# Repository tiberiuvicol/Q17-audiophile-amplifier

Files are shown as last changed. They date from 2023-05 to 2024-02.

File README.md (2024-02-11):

# Q17-an audiophile approach to perfect sound

<a href="https://github.com/tiberiuvicol/Q17.3">Q17.3 is the latest implementation</a>

Q17

Q17 is a class B amplifier based on current dumping principle.<br>
Please refer to <a href="https://github.com/tiberiuvicol/Q17-audiophile-amplifier/blob/main/Project%20description.pdf">Project description.pdf</a> for project description.<br>
Use KiCad 6, or later, to open and edit source files.  KiCad 6 can be downloaded from CERN, https://www.kicad.org<br>
<b>LTSpice</b> - contain simulation asc file<br>
<b>Q17.7z</b> - <a href="https://forum.kicad.info/t/simulation-examples-for-kicad-eeschema-ngspice/34443">ngspice simulation</a> files for Q17. This will run directly in KiCad. Thank you, Holger Vogt !<br>
<b>KiCad source PS</b> - active rectification power supply KiCad source files<br>
<b>KiCad source</b> - Q17 amplifier KiCad source files<br>
<b>Q17_2final</b> - Q17 amplifier KiCad source files for dual output stage<br>
<b>Q17.pdf</b> - detailed presentation - bill of materials included<br>
<b>gerber-ps.zip</b> - production gerber for PCB active rectification power supply<br>
<b>Q17-Gerber.zip</b> - production gerber for Q17 amplifier with single output pair<br>
<a href="https://github.com/tiberiuvicol/Q17-audiophile-amplifier/blob/main/Q17-gerber-2pair.zip"><b>Q17-gerber-2pair.zip</b></a> - production gerber files for Q17 with dual output pair stage<br>
<b>Q17_dimensions.pdf</b> - PDf file with most important PCB dimensions<br>
Important ! - Amplifier is more stable with R32=0ohm



<br>
Click & Order your Q17 with dual output pair PCB @ <a href="https://www.pcbway.com/project/shareproject/Q17__a_QUAD405_audiophile_approach.html">PCB from PCBWay</a><br>
Purchase parts (for one channel) with one click from mouser ->> https://www.mouser.com/ProjectManager/ProjectDetail.aspx?AccessID=1f37a45393 <br>
For STEREO or MULTICHANNEL multiply the order with the same parts. <br>
<br>
<br>
<b>Q&A collected from mail</b><br>
<br>
Q: Why no dc blocking input capacitor?<br>
A: <i>Please consider that Q17 first stage make use of an operational that have a C7=1uF capacitor in negative loop. <br>
This already make a dc block and we have a non polar capacitor C2&C22 in dc servo as well.<br>
On other hand, if there is any dc at amplifier input, you should look on your audio source and eliminate it. Do not try to “solve” previous stage problems by "playing safe" at the amplifier input.</i><br>
<br>
<br>
Q: Why no voltage/ESD input protection ?<br>
A: <i>A voltage/ESD can be made by using zener or reverse polarised diodes. The issue with this approach is that any reverse polarised p/n junction (diode etc) will have high parasitic capacitance modulated by voltage and this highly degrade amplifier performance. How to work around this ? Use a good R-2R Volume Controller with constant output impedance.</i><br>
<br>
<br>
Q: Any amplifier need input LPF, otherwise EMI will affect SNR.  Q17 do not have one, therefore it is poorly designed. Why Q17 do not have input LPF?<br>
A: <i>Please do not generalise. The world is not black and white.The role of LPF is to block any unwanted frequencies to enter in amplifier. <br>
A LPF must be designed such way that will not be affected by input impedance. This is not the case with a potentiometer. Does not matter how good this potentiometer is, his attenuation will affect LPF and therefore amplifier bandwidth. This is very audible at low level volume.<br>
The classic way on how a potentiometer is implemented, is that he offer constant input impedance and variable output impedance toward amplifier input. The down side is that, even you go for a high input impedance, at low audio levels input LPF will reach audio band affecting amplifier bandwidth. This is translated in poor audio performance at low audio levels.<br>
This issue was addressed in Maya volume controller that make use of an R-2R resistive network allowing constant output impedance with high input variable impedance.<br>
Beside this, input cable parasitic capacitance together with high amplifier impedance is enough to form a HF-LPF. Output operational LPF at ~125KHz will clean any noise further.</i><br>
<br>
<br>
Q: Could you please recommend me a potentiometer ?<br>
A: <i>Best attenuator will be a R-2R one with constant output impedance. If you want to go cheap please use a 50K log ALPS.</i>
<br>
<br>
Q: Why there is no super diode ?<br>
A: <i>A super diode is usually made with a BJT, where his Vbe variation with temperatures is used to adjust output stage bias. Unfortunately this is highly nonlinear and will modulate, with Vcb voltage (again reverse polarised p/n junction), output stage bias. While this is very efficient, will highly degrade audio performance. My preference is to have plain and simple resistors, with no capacitor decoupling between output mosfet gates.</i><br>
<br>
<br>
Q: What about transitory power ON/OFF ? <br>
A: <i>For this there are Q13&Q14. These have double role.<br>
One is to ensure soft start and soft power off using RC made with R29C13 and R30C14. <br>
This can be seen at amplifier turn on, D1 & D4 will light after ~1s.<br>
Second role for Q13&Q14 is to act as super-capacitors, ensuring smooth power supply for class A and input stage.</i><br>
<br>
<br>
Q: Why no protection zeners on all mosfets ?<br>
A: <i>Some mosfets need Vgs protection while other do not need.<br>
Let’s start with ones that do not need and later the ones that may need.<br>
Q1 and Q4 are part of regulators and Vgs is already limited by 18V zeners.<br>
Q8 is part of cascode and his Vgs is already limited by positive zener regulator to 18V. You may say it is high, but Q8 source is already lifted above ground by Q7.<br>
Q9 and Q11 are part of current mirror. Q9’s Vgs is limited by Q10 + Vbe and Q10 by Q9 Vgs + VR3. This will not exceed 4V.<br>
Q5 Vgs is also limited by Q9 Vds + VR3. Where Q9 Vds = Q10 Vgs. Therefore, mirror with Q9&Q10 act as Vgs limiter for Q5.<br>
Q6 may need a zener to limit his Vgs due during a transitory turn on his Vgs may be higher, but for a soft turn on there are Q13&Q14.<br>
Q13&Q14 obviously need Vgs limiters because at power on, while C13&C14 are charging, Vgs will be above 45V. For such reason there are zener D4&D5, limiting Vgs to a value that keep Q13&Q14 on safe side.<br>
Q15&Q16&Q17&Q18 are output transistors that may need protection zener. These are high transconductance mosfets that indeed will deliver very high transitory currents. Here the man advantage is that we are running these in class B with very low bias current. Turn on/off transitory is also softened by Q13&Q14 trough class A stage made with Q5&Q6.<br>
On other hand, I prefer to run output stage without protection zener, due any zener internal parasitic capacitance is modulated with voltage. Any reverse biased diode act like a varicap. This is translated in muddy highs.</i><br>
<br>
<br>
Q: Why no output inductor ?<br>
A: <i>This is a highly debatable question.<br>
I’m a nerd audiophile. I like good sound more than “playing safe”.<br>
However, your speaker cables have already an important inductance and parasitic capacitance that must considered. <br>
In some particular cases adding an output inductor may be needed, but these are very … few particular ones.<br>
To be short, Q17 with no coil sound better.</i><br>
<br>
<br>
Q: May I use Lateral MOSFET's in ouput stage ?<br>
A: <i>No, you do not, the PCB was designed for Vertical MOSFET. Lateral mosfet transistor's have different piout than Vertical MOSFET.<br>
  PCB need to be redesigned to accomodate Lateral's, for both Class A and output Class B stage.
  Laterals have lower Vgsth than Verticals, hence for laterals, R11 and R12 must be between 9.1 and 10 ohm.</i><br>
<br>
<br>
Q: Why no embedded protection in your schematic ?<br>
A: <i>This again due sound quality. There is always a trade between playing safe and having best sound.<br>
I like to have best sound even I do not play safe and currently market offer a wide range of speaker protection modules.<br>
Simplest protection would be to use a fast fuse (3A-5A) at amplifier output.</i><br>
<br>
<br>
Q: How much capacitance I may put in power supply ?<br>
A: <i>This is related to your power transformer. A huge capacitance must be charged to be efficient.  For a transformer with 3A in secondary, I would say 20mF per rail is enough.</i><br>
<br>
<br>
Q: Is there any sound difference between a normal bridge and Saligny synchronous rectifiers ?<br>
A: <i>Yes, Saligny rectifiers are far superior and bring important sonic improvement.</i>
<br>
<br>
Q: It is Q17 quiet ?<br>
A: <i>Yes it is. No fass no buzz, even with high SPL speakers >95dBm.</i><br>
<br>
<br>
Q: May you recommend a transformer ?<br>
A: <i>Any well made 300VA transformer, with 2 separate secondaries at min.36Vac - max.42Vac.</i><br>
<i>For my projects I order at https://petra-toroid.ro/?lang=en they ship worldwide.</i><br>
<i>How to order:</i><br>
<i>- go to https://petra-toroid.ro/contact/?lang=en use form or email</i><br>
<i>- mention that you want to order one or two 300VA trafo</i><br>
<i>- primary 115Vac or 230Vac, depending on the mains voltage in your region</i><br>
<i>- 2 separate 36Vac secondaries</i><br>
<i>- optional magnetic shielding</i><br>
<i>- mention that application will be for audio</i><br>
<i>Other sources are: https://www.audiophonics.fr/en/toroidal-transformers/toroidal-transformer-300va-2x38v-p-5548.html</i><br>
<i>Toroidy https://sklep.toroidy.pl/en_US/c/Toroidal-transformers-SUPREME-AUDIO-GRADE-V2/99</i><br>
<i>Trafco http://www.trafco.rs/torusni-en.php</i><br>
<br>
<br>
Q: Can Q17 drive ESL speakers ?<br>
A: <i>Yes, will drive ESL speakers very well. Thanks to high transconductance mosfet’s, Q17 will offer excellent performance on ESl speakers.</i><br>
<br>
<br>
Q: What make Q17 special ?<br>
A: <i>His topology, class B operation, PCB with embedded coil and innovative active power supply. </i><br>
<br>
<br>
Q: Is Q17 power eficient ?<br>
A: <i>Yes, it is. Thanks to class B operation and Saligny synchronous rectification, Q17 is a modern amplifier with low power consumption.</i><br>
<br>
<br>
Q: My left channel is warmer, ~5Celsius, than the right channel. How I can match them ?<br>
A: <i>Is this a really issue ? No.
Left/Right channel temperature difference is mainly due slightly different "bias" in output stage. Even Q17 is running in class B, each mosfet have different Vgs treshold and this is translated in more or less Ids current. You may start by matching Q12 to have very appropiate Vbe's, than make sure R11, R12, R13 are matching R11, R12, R13 from other channel. Finnaly, match output Q15 .. Q18 mosfets between channels.</i><br>
<br>
<br>
Q: Voltage over R3 should be around 0.6Vdc, but mine is way off, how may I adjust this ?<br>
A: <i>In order to have 0.6Vdc over R3, Q9 and Q11 must be matched (same Vgth), only then voltage over R3 is given only by Q10Vbe. Therefore please match Q9 and Q11 to have same Vgsth=Voltage gate to source threshold. </i><br>
<br>
<br>
Q: Where you you place this amplifier in term of value ?<br>
A: <i>A well executed Q17, will be better or at least on pair with some $5 digit amplifiers.</i><br>
<br>
<br>
Thank you for reading ! <br>
If you have built this amplifier I would love to see your Q17 implementation. :-) <br>
<br>
Many thanks to those who built Q17 and shared their experience. Here is the builders feedback:<br>
https://www.diyaudio.com/community/threads/q17-an-audiophile-approach-to-perfect-sound.374507/page-72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
<br>
https://www.diyaudio.com/community/threads/q17-an-audiophile-approach-to-perfect-sound.374507/page-114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
<br>

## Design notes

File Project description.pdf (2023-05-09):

Q17 - audiophile approach to perfect sound

Hard to prove statements:
I know what I saw ! Ufologist I know what I hear ! Audiophile

by audiophile Tiberiu Vicol & ChatGPT This document was updated on 09.May.2023

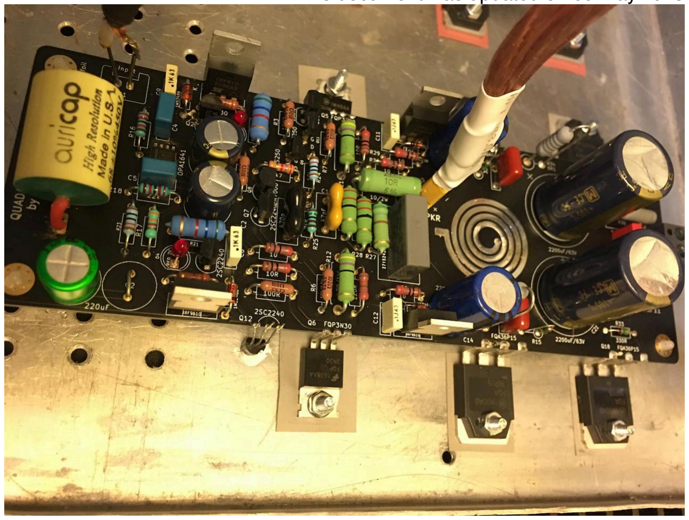
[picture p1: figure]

Introduction:

Q17 is a class B amplifier based on the current dumping principle.

Initial technical requirements:

- Stable operation: The amplifier must remain stable under any operational condition, with no oscillation.
- Minimum 100W in 8ohm at 1kHz: This should be sufficient for audiophiles with "impossible to drive" speakers.
- Frequency response cutoff of 10Hz - 100kHz: This will allow for a decent slew rate.

- IMD (Inter-Modulation Distortion) under 0.01%
- THD (Total Harmonic Distortion) under 0.01% at 1W and full power
- Design must be affordable, using readily available THT or SMD components or equivalents.
- Cost-effective and easy to build: High-end audio must be affordable.
- Open source: Let's offer everything - schematic, simulation, source PCB files, and bill of materials.
- Designed using LTspice simulation with final touch by extensive bench measurements and testing. Starting with KiCad 6.0.2, ngspice simulation is possible, and files have been made available by Holger Vogt: https://forum.kicad.info/t/simulation-examples-foricad-eeschema-ngspice/34443 (https://forum.kicad.info/t/simulation-examples-for-icad-eeschema-ngspice/34443)
- Final design decisions are always made using my platinum
ears. ;-) This means that Q17 is designed by comparing different topologies, and the final decision is taken not by measurement, but by listening. Q17 is indeed designed by ear. :-D

And here are the on-ear requirements:

Sound quality is of paramount importance. The amplifier must sound excellent at any level, without causing listening fatigue. The sound must be vivid, with a full body and plenty of harmonics with long decay, while maintaining resolution and clarity from top to bottom. Each instrument must sound natural, clearly separated, and easy to locate in space, even in large orchestras.

- No hiss or buzz: Poor rectification and filtering may result in unwanted noise.
- Microdynamic: This is challenging. The rhythm must be clear and distinct at any volume. I don't want flat, compressed, or lifeless sound. This is often related to negative feedback (NFB). In my opinion, NFB is only partially true, and it largely depends on how it is used along with other factors. High-quality power supply filter capacitors may also help.
- Macrodynamic linearity: The amplifier must be capable of going from low to high power levels instantly, without distortion or compression. It must provide the feeling of unlimited power. This is mainly related to the power supply. If the amplifier is capable of delivering power, the power supply must be able to handle it as well.

- Resolution: I prefer an amplifier that offers both resolution and fullbodied instruments, without losing harmonics and decay. Welldesigned single-ended direct-heated triodes (SEDHT) are capable of achieving this, and I want the same from my amplifier. I know this is another challenging requirement. Intermodulation distortion plays a role here. Low IMD always leads to top resolution, but sometimes musicality can be lost.

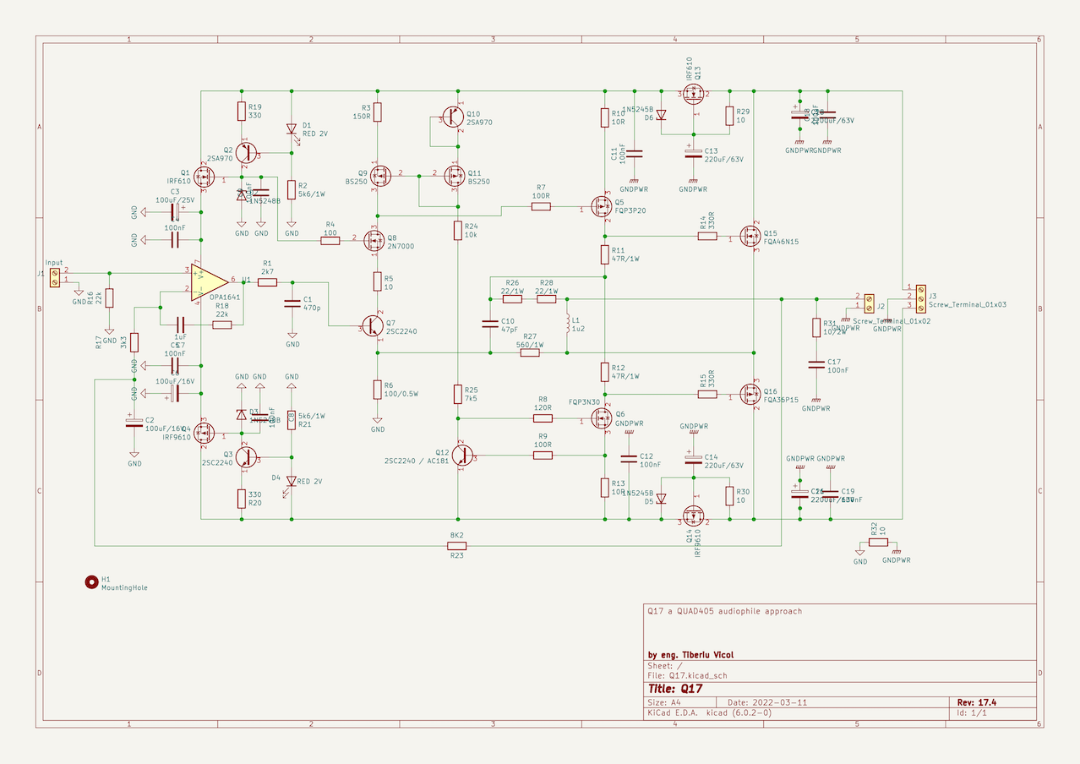
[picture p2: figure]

Q17 with output single pair of Fairchild’s

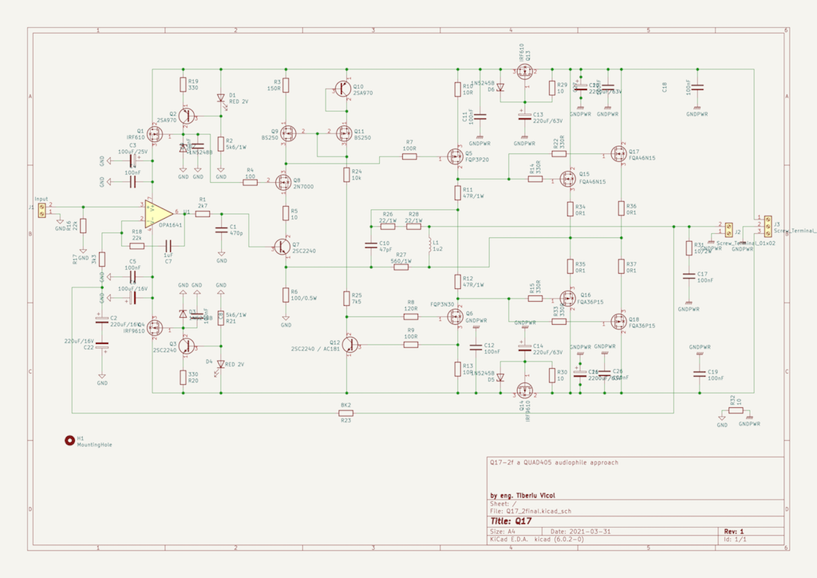
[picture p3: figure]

Q17 with output double pair of Fairchild’s

## Functional Description:

### Q17 is designed to deliver music at the highest audio performance, and

this design does not follow the "amplifier design book." Intentionally,

### the input is DC coupled, it has no input LPF, and does not make use of diodes or Vbs multiplier for thermal compensation. Q17 will run in class B, even though the output devices are MOSFETs with a very high Vgs

threshold. As far as I know, this has never been attempted before.

### Please correct me if I'm wrong. Q17 is divided into two separate

sections, which we will call Section One and Section Two.

Section One is made with the operational amplifier OPA1641. Today,

OPA1641 is one of the best opamps on the market. In fact, it is so good that a discrete circuitry will barely come close. OPA1641 is a JFET input operational amplifier that, apart from technical specifications, sounds very good and is cost-effective too. We are not driving a low impedance output, and there are no thermal issues. Those who do not like JFET

sound may try LME49990. This sounds great as well.

In my humble opinion, phase accuracy is very important. Therefore,

Q17 is not inverted and will preserve the original phase of the signal.

The input impedance is given by R16 = 22K. This is a good trade between high impedance and thermal resistor noise. You want higher input impedance? You can go as high as 47K. Use a good metal foil resistor here, and it should be enough. R17 and R18 are part of operational negative feedback and will set the gain to (R17+R18)/ R17=7.6. Many operational amplifiers will not be stable at low gain, and the stability limit is usually at a gain higher than 5. 7.6 will offer good

sensitivity, and we are on the safe side, away from any oscillation.

### Through R30, R25, and C3, the input operational will have a second role, acting as a DC servo. C3 must be bipolar, and I recommend using a good one like Nichicon MUSE. However, two normal polarized electrolytics connected in series will work just fine. For this use, low-

voltage electrolytics in the range of 6.3V-10VDC.

### R1C1 forms a low-pass filter with a cutoff frequency of 125kHz. This RC filter is the main load for the operational and will also limit the whole

amplifier's full bandwidth. C1 must be silver-mica or polystyrene.

### The operational is fed by two "reasonably low noise" regulators. The operational will not draw more than 10mA per raw, but its sonic

performance is highly dependent on the quality of these regulators. So,

### I have invested some time and parts to get the best topology for sound

versus price compromise.

Here is how it works. Regulation is ensured by 18V zeners D2 and D3, which are fed by a constant current source at around 4.2mA. Q2, D1,

### R19, and R2 (respectively Q3, D4, R20, and R21 for the negative rail) form a simple current source. D1 and D4 are red LEDs with Vf~2V. It is well-known that an LED is a reliable low-noise voltage reference. The current through the zener diode will be (LedVf-Q7Vbe)/R19 = (2-0.6)/330

= 4.2mA. This reference voltage is used by two MOSFETs, Q1 and Q4,

### respectively, to deliver higher current to OPA1641. IRF610/IRF9610 are a bit overkill here but are easy to find and cheap enough. These will run

warm but do not need a heatsink.

### Here is one of my first audiophile observations: MOSFET regulators sound better than bipolar regulators. They do not measure better, but

they sound better.

### Section two starts with a cascode formed by Q7 and Q8. This stage offers high gain, high output impedance, and high open-loop bandwidth

and may be a challenge to keep it out of oscillation. For this reason, R5 is there. This will lower the gain and increase stability at the cost of some distortion. In place of Q7, some inexpensive transistors BC5xx/ BC8xx can be used, as maxVce > 45V is the only restriction. From a sonic point of view, some cascodes may kill the "soul of music," in other words, offer a less vivid sound. Things are going far better if you use a MOSFET as the top active device. This will preserve dynamics at

any level.

### The cascode - Q7 & Q8 - stage has a high output impedance, therefore

it is fed by a constant current source made by Q10 and R3 at approx.

### 4.5mA. Q10 can be any low-cost, high-beta PNP BJT. Yes, any PNP, no

constraints.

### The CCS current is mirrored to Q12 by Q9 & Q11 through R24 & R25. In fact, the heart of Q17 is around this CCS+ current mirror. A current mirror that can be made with high-beta PNP transistors or P-channel MOSFET. You may need to pair these transistors to have same Vbe or

Vgs at ˜5mA.

I tried both. BJT mirror is very precise and offers a lush sound. For MOSFET, I used BS250P, and in this case, sound is deeper with a better midrange. Micro-dynamics seem to be higher too. After extensive listening sessions and some burn-in, I can confidently say that I will stay with MOSFET mirror. Take care of BS250P numbering termination as

this is different for manufacturers - see Vishay and Diodes.

### Instead of R24 & R25, you may use a single 1W resistor. This was split

in two to distribute power dissipated.

### Next is a class A stage. Here a single modern high-transconductance

MOSFET will do an excellent job, at the cost of some input capacitance.

### MOSFETs create more even-order harmonics compared to bipolar's too. As I care more about harmonic content than THD, here is my

preference for MOSFET.

### The quality of these MOSFETs may dramatically influence the amplifier's sonic signature, and these have been chosen after long

listening sessions.

### The P-channel MOSFET Q5 is a class-A active device, and from my observation, the P-channel FQP3P20 is slightly more linear than the Nchannel FQP3N30. However, at the current time (2021), we do not have

too many options. Toshiba's lateral MOSFETs (2SJ76, 2SJ77, 2SJ78,

### 2SJ79, and 2SK213, 2SK214, 2SK215, 2SK216) have long been obsolete. If you can source them, use them, but don't set your

expectations too high. These will not sonically exceed the FQP's.

### However, if you do use them, some capacitor compensation may be

needed to keep them from oscillating.

Q5 is fed by a 60mA CCS formed by Q12 and Q6. Q12 Vbe is the main reference in this CCS and can be used as thermal compensation for the final stage too. Again, there are no constraints for Q12. It can be any high-beta, low-voltage, NPN BJT. The CCS current can be calculated by Q12Vbe/R13 and would be around 60mA. This will push Q5's operation in class A and offer enough juice to drive the final dumper stage. Q5 and Q6 will dissipate 3W and must be mounted on a

heatsink.

### Q12 must also be mounted on a heatsink as it will be used to

compensate for final stage thermal runaway.

### Changing R13 to 2 ohms, a germanium AC181 can be used here as better temperature compensation. I must mention that this mod will not bring "germanium sound" into this amplifier. Sorry, germanium lovers!

### R9 is there as a base stopper and to avoid any possible oscillation. R7

and R8 are gate stoppers too.

### The Q17 amplifier runs in class B. There is no bias needed, and the Q17

amplifier may accept a very wide range of output MOSFET transistors.

Choosing the final pair Q15 & Q16.

I'm a big fan of lateral MOSFETs made by Semelab-Semefab-Exicon-Magnatec, whatever company is behind. This Scottish company is one of the last to make very good high-power lateral MOSFETs. I proudly used them in many amplifiers, and they sound exceptional. The main goal of Q17 is to be affordable, and these laterals, like many other good things, are not so cheap. They are very rugged and allow a high level of

"torture" and make things sometimes easy. No protections are needed.

### But... there is a "but." They have a small transconductance. You need to use double die and parallel a few of them to get some decent transconductance because audiophile speakers make use of

### complicated crossovers that like a lot of current in the most unexpected

frequencies.

Fairchild, now ON Semiconductor, was a great company and one of their legacies is FQA46N15 and FQA36P15. If you think these are P/N pairs, you are wrong. There is no such P/N perfect match in the real world, but we can choose the closest ones. These are marketed as "Fairchild Semiconductor's proprietary planar stripe and DMOS technology," with a small remark that they may be suitable for audio

amplifiers as well.

### FQA46N15 has a regular transconductance of 36 Siemens, while Exicon double die ECW20N20 has a maximum of 4 Siemens. This is equivalent to 9 double die laterals. Yes, very impressive! FQA36P15 has a regular transconductance of 19.5 Siemens, while Exicon double die ECW20P20

has a maximum of 4 Siemens. This is equivalent to 4 double die laterals.

In the "dark side" of Mouser, some beasts may leave these Fairchild's in the dust. These are made by IXYS, and a pair could be IXFK220N20X3 and IXTK120P20T. These exhibit over 120 Siemens of transconductance and are capable of transforming your amplifier into a real welding machine. No joke at all. If your speakers have never been

moved before, use a pair of these and shake your world, your walls, your neighbor...

### Through R11 and R12, these devices will be biased near class A operation. Both FQA46N15 and FQA36P15 have a Vgs - threshold voltage between 3V and 4V. I found that the P channel FQA36P15 will

open around 3V, while the FQA46N15 will need 100mV-300mV more.

### (To have both running at the same level, R11 may be increased to 51ohm or more.)

### Obviously, Q15 and Q16 must be mounted on a large heatsink. R31C17 is the well-known Zobel filter. C17 quality is important. Use a good propylene or polystyrene capacitor here. My preference is polystyrene Multicap RTX series. If you do not want to invest too much, go for

Arcotronix.

### R26, R27, R28, C10, and L1 form the current dumping bridge. R27 and R6 are part of section 2 negative feedback. This sets the entire amplifier gain to [(R17+R18)/R17]x[{R27+R6)/R6]=45.6, enough for the amplifier

to reach 100W/8ohm at 0.7V input.

### Q13 and Q14 are capacitor multipliers and are there to reduce power supply ripple. (These are not needed if you use synchronous rectification - see below.) During power on, the gate to source voltage on Q13 and Q14 may easily exceed 10V and may damage these

MOSFETs. For this reason, D5 and D6 are there to protect.

### You may have noticed that there are R4, R7, R8, R9, R14, and R15 as gate or base stoppers. I always prefer gate stoppers to compensate with capacitors. R32 will separate the signal ground plane from the

power ground plane. There are no special requirements for this one.

### Please note that R32 is 0ohm and not 10ohm as in presented

schematic.

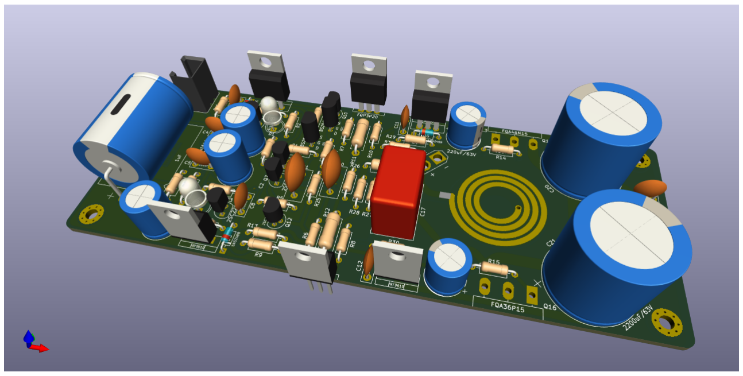
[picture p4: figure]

PCB design

During the COVID-19 lockdown, I had enough time to learn KiCad. KiCad runs on any operating system and is open source. This offers flexibility, scalability, and security. KiCad is a great tool.
I have designed this project in KiCad 5.99-nightly. To open the files, you need at least 5.99. This is already compatible with the upcoming KiCad 6, which is a huge step forward.
I opted for separate small and high signal ground planes. Ground planes are a good solution to avoid ground loops and offer excellent EMI reduction. For the best noise reduction, small signal GND makes use of top and bottom ground planes.
The PCB embeds an L1 inductor that is part of the error correction bridge. This will ensure good tolerance and optimal geometric design.

Yes, a PCB inductor will have the right shape for a near-to-ideal inductor. The truth is that I'm lazy to wire-wind coils. Having this embedded in the PCB will help lazy people like me a lot, but what I said earlier is still valid. A PCB coil is better. In a separate document, I have detailed how to create and embed inductors in KiCad.
The PCB offers the option to install several C7 types. Use propylene at any voltage > 50V. C17 must be propylene, preferably FKP, or polystyrene at a voltage > 100V.
OPA1641 is the single SMD part, and the PCB does not offer the option to install a THT one. But as long as I offer the source files for this project, you are invited to modify and redesign as you wish.

Bill of materials for Q17

D1,4 - LED RED 2V - https://ro.mouser.com/ProductDetail/Vishay-Semiconductors/TLHR5200?qs=GMckgg3bfZPthGr1cDR0RA%3D%3D (https://ro.mouser.com/ProductDetail/Vishay-Semiconductors/TLHR5200?qs=GMckgg3bfZPthGr1cDR0RA%3D%3D) D2,3 - 1N5248B - https://ro.mouser.com/ProductDetail/ON-Semiconductor-Fairchild/1N5248B?qs=G5AQjGfRJcJY58VFTX%252BkdQ%3D%3D (https://ro.mouser.com/ProductDetail/ON-Semiconductor-Fairchild/1N5248B?qs=G5AQjGfRJcJY58VFTX%252BkdQ%3D%3D)
D5,6 - 1N5245 - https://ro.mouser.com/ProductDetail/ON-Semiconductor-Fairchild/1N5245BTR?qs=jumAldekxNAufOthuRVeGQ%3D%3D (https://ro.mouser.com/ProductDetail/ON-Semiconductor-Fairchild/1N5245BTR?qs=jumAldekxNAufOthuRVeGQ%3D%3D)
Q7,12 - KSC1845 - https://ro.mouser.com/ProductDetail/ON-Semiconductor-Fairchild/KSC1845FTA?qs=UMEuL5FsraDCmxWozTypUA%3D%3D (https://ro.mouser.com/ProductDetail/ON-Semiconductor-Fairchild/KSC1845FTA?qs=UMEuL5FsraDCmxWozTypUA%3D%3D)
Q8 - 2N7000 - https://ro.mouser.com/ProductDetail/ON-Semiconductor-Fairchild/2N7000TA?qs=iN0KuJO79KZfCWVKA48bEg%3D%3D (https://ro.mouser.com/ProductDetail/ON-Semiconductor-Fairchild/2N7000TA?qs=iN0KuJO79KZfCWVKA48bEg%3D%3D)
Q2,Q10 - KSA992 - https://ro.mouser.com/ProductDetail/ON-Semiconductor-Fairchild/KSA992FBTA?qs=BiJXFBt7cx0C7PSFUPmr1w%3D%3D (https://ro.mouser.com/ProductDetail/ON-Semiconductor-Fairchild/KSA992FBTA?qs=BiJXFBt7cx0C7PSFUPmr1w%3D%3D)
Q9,11 - BS250P - https://ro.mouser.com/ProductDetail/Diodes-Incorporated/BS250P?qs=OlC7AqGiEDnRUFCQhRDfhA%3D%3D (https://ro.mouser.com/ProductDetail/Diodes-Incorporated/BS250P?qs=OlC7AqGiEDnRUFCQhRDfhA%3D%3D)
Q1,13 - IRF610 - https://ro.mouser.com/ProductDetail/Vishay-Siliconix/IRF610PBF-BE3?
qs=%2Fha2pyFadugbZUitPAu%252BTEPjT5SopLZ8qDnf9IMIvY8%3D (https://ro.mouser.com/ProductDetail/Vishay-Siliconix/IRF610PBF-BE3) Q4,14 - IRF9610 - https://ro.mouser.com/ProductDetail/Vishay-Semiconductors/IRF9610PBF?qs=cvaI6ThkwxtWoLkQbU%2FdsA%3D%3D (https://ro.mouser.com/ProductDetail/Vishay-Semiconductors/IRF9610PBF?qs=cvaI6ThkwxtWoLkQbU%2FdsA%3D%3D) Q5 - FQP3P20 - https://ro.mouser.com/ProductDetail/onsemi-Fairchild/FQP3P20?qs=mdiO5HdF0Ki1WoTNCOatYg%3D%3D (https://ro.mouser.com/ProductDetail/onsemi-Fairchild/FQP3P20?qs=mdiO5HdF0Ki1WoTNCOatYg%3D%3D)
Q6 - FQP3N30 - https://ro.mouser.com/ProductDetail/onsemi-Fairchild/FQP3N30?qs=FOlmdCx%252BAA1dVHDhvU%252BUcw%3D%3D (https://ro.mouser.com/ProductDetail/onsemi-Fairchild/FQP3N30?qs=FOlmdCx%252BAA1dVHDhvU%252BUcw%3D%3D)
Q15 - FQA46N15 - https://ro.mouser.com/ProductDetail/ON-Semiconductor-Fairchild/FQA46N15?
qs=%2Fha2pyFaduimCeOyuw0xouriGUKJcVVjoz%2FqQ0BKQtc%3D (https://ro.mouser.com/ProductDetail/ON-Semiconductor-Fairchild/FQA46N15) Q16 - FQA36P15 - https://ro.mouser.com/ProductDetail/ON-Semiconductor-Fairchild/FQA36P15?
qs=%2Fha2pyFadugPFcM3hvKrsP2cJsnMpKcpv1XDSGf5JCo%3D (https://ro.mouser.com/ProductDetail/ON-Semiconductor-Fairchild/FQA36P15)

U1 - OPA1641 - https://ro.mouser.com/ProductDetail/Texas-Instruments/OPA1641AIDR?
qs=sGAEpiMZZMutXGli8Ay4kFRPeV04IrZfqfNgaiEGnmE%3D (https://ro.mouser.com/ProductDetail/Texas-Instruments/OPA1641AIDR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)

C17 - 100nF - https://ro.mouser.com/ProductDetail/KEMET/R76MI31005050J?qs=pUKx8fyJudAaVipAdJ8Rqw%3D%3D (https://ro.mouser.com/ProductDetail/KEMET/R76MI31005050J?qs=pUKx8fyJudAaVipAdJ8Rqw%3D%3D) C4,5,8,9,11,12,18,19 - 100nF - https://ro.mouser.com/ProductDetail/KEMET/PHE426DJ6100JR05?qs=PoZJcSwa6DzVkLIswxOBtw%3D%3D (https://ro.mouser.com/ProductDetail/KEMET/PHE426DJ6100JR05?qs=PoZJcSwa6DzVkLIswxOBtw%3D%3D)
C10 - 47pF - https://ro.mouser.com/ProductDetail/Cornell-Dubilier-CDE/CD15ED470JO3?qs=JlSiUoO6twmzsCndHIj%2FhA%3D%3D (https://ro.mouser.com/ProductDetail/Cornell-Dubilier-CDE/CD15ED470JO3?qs=JlSiUoO6twmzsCndHIj%2FhA%3D%3D)
C7 - 1uF - https://ro.mouser.com/ProductDetail/Cornell-Dubilier-CDE/930C1W1K-F?qs=oi6qnwyrdkzUKQFAck35kQ%3D%3D (https://ro.mouser.com/ProductDetail/Cornell-Dubilier-CDE/930C1W1K-F?qs=oi6qnwyrdkzUKQFAck35kQ%3D%3D)
C1 - 470pF - https://ro.mouser.com/ProductDetail/Cornell-Dubilier-CDE/CD15FD471JO3F?qs=FKrQhPEeH%252B6Y%2FhdJiMfeDw%3D%3D (https://ro.mouser.com/ProductDetail/Cornell-Dubilier-CDE/CD15FD471JO3F?qs=FKrQhPEeH%252B6Y%2FhdJiMfeDw%3D%3D) C2 - 100uF BP - https://ro.mouser.com/ProductDetail/Nichicon/UES1C101MPM1TD?qs=JgOBn5pVFoqelxyCFlUB6Q%3D%3D (https://ro.mouser.com/ProductDetail/Nichicon/UES1C101MPM1TD?qs=JgOBn5pVFoqelxyCFlUB6Q%3D%3D)
C3,6 - 100uF/25V - https://ro.mouser.com/ProductDetail/Vishay-Sprague/510DX107M025CC2D?qs=j9BvaggtyN3XWy0%2FfD7iig%3D%3D (https://ro.mouser.com/ProductDetail/Vishay-Sprague/510DX107M025CC2D?qs=j9BvaggtyN3XWy0%2FfD7iig%3D%3D) C13,14 - 220uF/63V - https://ro.mouser.com/ProductDetail/Vishay-BC-Components/MAL215058221E3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 (https://ro.mouser.com/ProductDetail/Vishay-BC-Components/MAL215058221E3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) C15,16,20,21 - 2200uF/63V - https://ro.mouser.com/ProductDetail/Nichicon/UPW1J222MHD?
qs=sGAEpiMZZMvwFf0viD3Y3V%252BktQc2dZjNU8%252BcKz5%2FjOU%3 D (https://ro.mouser.com/ProductDetail/Nichicon/UPW1J222MHD)

R1 - 2k7 - https://ro.mouser.com/ProductDetail/Vishay-Dale/CCF072K70JKE36?qs=QKEOZdL6EQrf8lXj1m%2FHqg%3D%3D (https://ro.mouser.com/ProductDetail/Vishay-Dale/CCF072K70JKE36?qs=QKEOZdL6EQrf8lXj1m%2FHqg%3D%3D) R2,21 - 5k6 - https://ro.mouser.com/ProductDetail/Vishay-BC-Components/PR01000105601JR500?qs=LCMWAU1DZcyMK8Yz0ZAhmQ%3D%3D (https://ro.mouser.com/ProductDetail/Vishay-BC-Components/PR01000105601JR500?qs=LCMWAU1DZcyMK8Yz0ZAhmQ%3D%3D) R24 - 10k - https://ro.mouser.com/ProductDetail/Vishay-Beyschlag/MBB02070C1002FRP00?qs=Jr4%2Ft4s12JUmAfKOFUNhig%3D%3D (https://ro.mouser.com/ProductDetail/Vishay-Beyschlag/MBB02070C1002FRP00?qs=Jr4%2Ft4s12JUmAfKOFUNhig%3D%3D) R3 - 150ohm - https://ro.mouser.com/ProductDetail/Vishay-Dale/CCF07150RJKE36?qs=Ad%252BIW%2FmDqmUeNbXSTmV5ZQ%3D%3D (https://ro.mouser.com/ProductDetail/Vishay-Dale/CCF07150RJKE36?qs=Ad%252BIW%2FmDqmUeNbXSTmV5ZQ%3D%3D) R5,10,13,29,30,32 - 10ohm - https://ro.mouser.com/ProductDetail/Vishay-Dale/CCF0710R0GKE36?qs=QKEOZdL6EQpP4bkfADZzbQ%3D%3D (https://ro.mouser.com/ProductDetail/Vishay-Dale/CCF0710R0GKE36?qs=QKEOZdL6EQpP4bkfADZzbQ%3D%3D) R4,6,7,9 - 100ohm - https://ro.mouser.com/ProductDetail/Vishay-Dale/CCF07100RJKE36?qs=NQWA6AwZmkMW4Ul%252BG32rNg%3D%3D (https://ro.mouser.com/ProductDetail/Vishay-Dale/CCF07100RJKE36?qs=NQWA6AwZmkMW4Ul%252BG32rNg%3D%3D) R8 - 120ohm - https://ro.mouser.com/ProductDetail/Vishay-Dale/CCF07120RGKE36?qs=QKEOZdL6EQrffKbi7vq1lg%3D%3D (https://ro.mouser.com/ProductDetail/Vishay-Dale/CCF07120RGKE36?qs=QKEOZdL6EQrffKbi7vq1lg%3D%3D)
R11,12 - 47ohm/2W - https://ro.mouser.com/ProductDetail/Vishay-Dale/CCF0247R0JKE36?qs=QKEOZdL6EQqc7KTqtOG%2FUA%3D%3D (https://ro.mouser.com/ProductDetail/Vishay-Dale/CCF0247R0JKE36?qs=QKEOZdL6EQqc7KTqtOG%2FUA%3D%3D) R16,18 - 22k - https://ro.mouser.com/ProductDetail/Vishay-Dale/CCF0722K0JKE36?qs=Ad%252BIW%2FmDqmUs0WVMJaSusw%3D%3D (https://ro.mouser.com/ProductDetail/Vishay-Dale/CCF0722K0JKE36?qs=Ad%252BIW%2FmDqmUs0WVMJaSusw%3D%3D)

R17 - 3K3 - https://ro.mouser.com/ProductDetail/Vishay-Dale/CCF073K30GKE36?qs=QKEOZdL6EQqcBZBx6GnZnQ%3D%3D (https://ro.mouser.com/ProductDetail/Vishay-Dale/CCF073K30GKE36?qs=QKEOZdL6EQqcBZBx6GnZnQ%3D%3D) R14,15,19,20,22 - 330ohm - https://ro.mouser.com/ProductDetail/Vishay-Dale/CCF07330RJKE36?qs=pkalMaiJWwv10%252BO%252BONxDWg%3D%3D (https://ro.mouser.com/ProductDetail/Vishay-Dale/CCF07330RJKE36?qs=pkalMaiJWwv10%252BO%252BONxDWg%3D%3D) R25 - 7K5 - https://ro.mouser.com/ProductDetail/Vishay-Dale/CCF077K50GKE36?qs=QKEOZdL6EQqRpabQIgr10Q%3D%3D (https://ro.mouser.com/ProductDetail/Vishay-Dale/CCF077K50GKE36?qs=QKEOZdL6EQqRpabQIgr10Q%3D%3D)
R23 - 8K2 - https://ro.mouser.com/ProductDetail/Vishay-Dale/CCF078K20GKE36?qs=QKEOZdL6EQrGlLmaSP0G2w%3D%3D (https://ro.mouser.com/ProductDetail/Vishay-Dale/CCF078K20GKE36?qs=QKEOZdL6EQrGlLmaSP0G2w%3D%3D)
R31 - 10ohm/2W - https://ro.mouser.com/ProductDetail/TE-Connectivity-Neohm/RR02J10RTB?qs=s1WWODT2SXW%252BZIrISq22ow%3D%3D (https://ro.mouser.com/ProductDetail/TE-Connectivity-Neohm/RR02J10RTB?qs=s1WWODT2SXW%252BZIrISq22ow%3D%3D) R26,28 - 22ohm - https://ro.mouser.com/ProductDetail/Vishay-Beyschlag/MBB02070C2209FCT00?
qs=sGAEpiMZZMsPqMdJzcrNwkfQgWkDJ%252BE2Mwj0n7JK2mo%3D (https://ro.mouser.com/ProductDetail/Vishay-Beyschlag/MBB02070C2209FCT00) R27 - 560ohm/1W - https://ro.mouser.com/ProductDetail/Ohmite/OM5615E-R58?
qs=sGAEpiMZZMukHu%252BjC5l7YREnR%2FWY87i1xVQq21Ltfa0%3D (https://ro.mouser.com/ProductDetail/Ohmite/OM5615E-R58)

J1 - input connector - https://www.hz-profishop.com/product_info.php?info=p701_mks-1651-6-0-202-s18--schwarz-.html (https://www.hz-profishop.com/product_info.php?info=p701_mks-1651-6-0-202-s18--schwarz-.html)
J2 - speaker output connector- https://ro.mouser.com/ProductDetail/DFRobot/FIT0586?qs=w%2Fv1CP2dgqouWR8IxqIK1w%3D%3D (https://ro.mouser.com/ProductDetail/DFRobot/FIT0586?qs=w%2Fv1CP2dgqouWR8IxqIK1w%3D%3D)
J3 - terminal block x 3 - https://ro.mouser.com/ProductDetail/Amphenol/TC0303620000G?qs=Mv7BduZupUgRMrlfdnWHCQ%3D%3D (https://ro.mouser.com/ProductDetail/Amphenol/TC0303620000G?qs=Mv7BduZupUgRMrlfdnWHCQ%3D%3D)

Extra parts for Q17-2f (Q17 amplifier with two output pairs)
R22, R33 - 330ohm https://ro.mouser.com/ProductDetail/Vishay-Dale/CCF07330RJKE36?qs=pkalMaiJWwv10%252BO%252BONxDWg%3D%3D (https://ro.mouser.com/ProductDetail/Vishay-Dale/CCF07330RJKE36?qs=pkalMaiJWwv10%252BO%252BONxDWg%3D%3D) R34,35,36,37 - 0.1ohm/3W https://ro.mouser.com/ProductDetail/TE-Connectivity-Holsworthy/ROX3SJR10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 (https://ro.mouser.com/ProductDetail/TE-Connectivity-Holsworthy/ROX3SJR10)
Q17 - FQA46N15 - https://ro.mouser.com/ProductDetail/ON-Semiconductor-Fairchild/FQA46N15?
qs=%2Fha2pyFaduimCeOyuw0xouriGUKJcVVjoz%2FqQ0BKQtc%3D (https://ro.mouser.com/ProductDetail/ON-Semiconductor-Fairchild/FQA46N15) Q18 - FQA36P15 - https://ro.mouser.com/ProductDetail/ON-Semiconductor-Fairchild/FQA36P15?
qs=%2Fha2pyFadugPFcM3hvKrsP2cJsnMpKcpv1XDSGf5JCo%3D (https://ro.mouser.com/ProductDetail/ON-Semiconductor-Fairchild/FQA36P15)

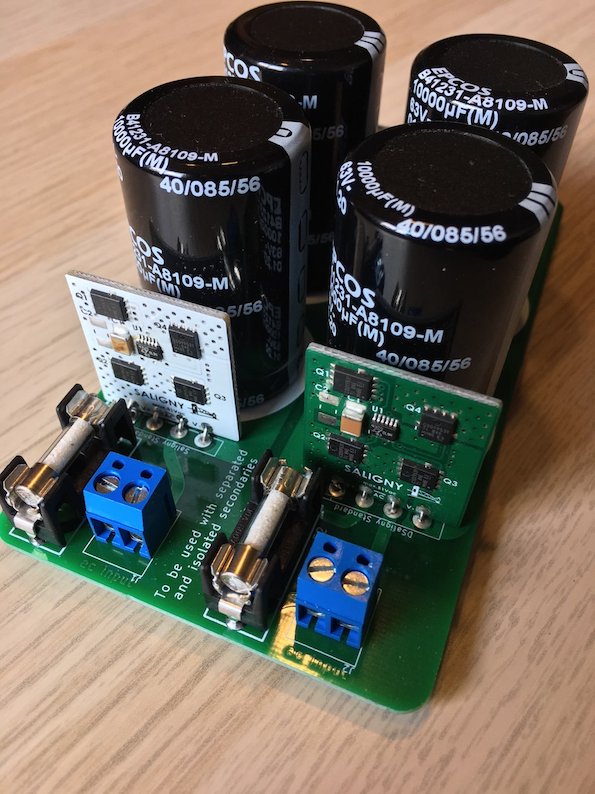
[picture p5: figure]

Active power supply

A good amplifier needs an exceptional power supply. All design efforts will be lost if we do not excel in this area too.

A diode is far from being a perfect device. There are no better devices, only better solutions.

Synchronous, or active rectification, has been available for a long time in professional appliances. The very first synchronous rectifier (mechanical rectifier) was used in the 1950s for high power and high voltage applications.

Its limited usage in consumer electronics was due to complexity and the very high cost involved. In recent years, thanks to green power requirements and electric vehicles, several dedicated chips have appeared in the consumer market. These mainly target PoE (power over Ethernet), but by choosing the right parts, the application can be extended to high-end audio as well.

A synchronous rectifier is a diode-less bridge employing modern MOSFET transistors that replace the four diodes in a full-wave bridge rectifier with a milliohm Rdson MOSFET, drastically reducing power dissipation, heat generation, voltage loss, and diode on/off switching noise. There is no P-N junction involved; only a low milliohm conductive channel is inserted in the power path. This allows for big current capability, better power management, less power loss, less dynamic impedance change versus load current, and better circuit performance than any available junction rectifier solution.

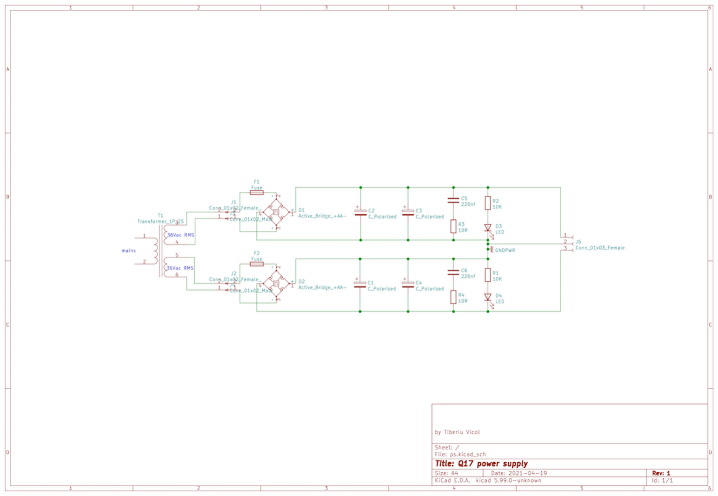
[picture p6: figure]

The advantage of using synchronous rectification is huge. While a normal diode has at least a 600mV drop at 1A, a low Rdson MOSFET will have as little as 3mV, or less, at the same 1A. This is 200 times better than a PN diode and at least 100 times better than a Schottky diode.

But how is this translated in audio? The most sensible difference is noise, due to synchronous rectifiers having negligible on/off noise. Each bridge MOSFET is acting like a soft on/off switch. The entire medium to top audio spectrum is cleaner. Voices are soft and cymbals full of harmonics. Another effect is better dynamics. The sound is more vivid because no power is lost in rectification or modulated by diode pn junctions, and the single current limiter is the intrinsic transformer resistance.

We make use of two Saligny Standard synchronous rectifiers made by Evotronix SRL. These are operated at 36Vac each, from a 300VA R-Core transformer. C1, C2, C3, C4 = 10000uF/63V are the main capacitor filters. There is a snubber formed with R3C5 and R4C6. This is needed only when normal diode bridge rectifiers are used. In our case with Saligny rectifiers, you may skip these parts. R2D3 and R1D4 are rail power indicators. A single power supply may be used for both Q17 modules, or two in case of a dual mono approach.

Bill of materials for power supply

J1,2 - terminal block x 2 - https://ro.mouser.com/ProductDetail/Amphenol/TC0203620000G?
qs=%2Fha2pyFaduhbuFfD6OHbCYxDpT0ma2Hwq0r2vPcUv6eC%2FlIp4UR n7Q%3D%3D (https://ro.mouser.com/ProductDetail/Amphenol/TC0203620000G)
J5,6 - terminal block x 3 - https://ro.mouser.com/ProductDetail/Amphenol/TC0303620000G?qs=Mv7BduZupUgRMrlfdnWHCQ%3D%3D (https://ro.mouser.com/ProductDetail/Amphenol/TC0303620000G?qs=Mv7BduZupUgRMrlfdnWHCQ%3D%3D)
C1,2,3,4 - 10.000uF/63V - https://ro.mouser.com/ProductDetail/EPCOS-TDK/B41231A8109M000?qs=f4aWRLuQiuxqY40YlReJiQ%3D%3D (https://ro.mouser.com/ProductDetail/EPCOS-TDK/B41231A8109M000?qs=f4aWRLuQiuxqY40YlReJiQ%3D%3D)
C5,6 - 220nF MKP - https://ro.mouser.com/ProductDetail/CDE-Illinois-Capacitor/MPX224K305E?qs=HXFqYaX1Q2wK3o1vUzHyKw%3D%3D (https://ro.mouser.com/ProductDetail/CDE-Illinois-Capacitor/MPX224K305E?qs=HXFqYaX1Q2wK3o1vUzHyKw%3D%3D) D1,2 - Synchronous Bridge - Saligny Standard - evotronix.eu
D3 - Red LED - https://ro.mouser.com/ProductDetail/Vishay-Semiconductors/TLHR5200?qs=GMckgg3bfZPthGr1cDR0RA%3D%3D (https://ro.mouser.com/ProductDetail/Vishay-Semiconductors/TLHR5200?qs=GMckgg3bfZPthGr1cDR0RA%3D%3D)
D4 - Green LED - https://ro.mouser.com/ProductDetail/Vishay-Semiconductors/TLHG5200?
qs=%2Fha2pyFadujruHm0H%252By%2FYe3hostfbxme%2F774XrUw9tU%3 D (https://ro.mouser.com/ProductDetail/Vishay-Semiconductors/TLHG5200)
R1,2 - - 10K/0,5W - https://ro.mouser.com/ProductDetail/Vishay-BC-Components/SFR16S0001002JA500?qs=H30XFsNYD%2FGypwPt5jX7ew%3D%3D (https://ro.mouser.com/ProductDetail/Vishay-BC-Components/SFR16S0001002JA500?qs=H30XFsNYD%2FGypwPt5jX7ew%3D%3D)
R3,4 - - 0 ohm - strap these if you use Saligny Standard
F1,2 - fuse holder - https://ro.mouser.com/ProductDetail/Littelfuse/0PTF0078P?qs=Co4VkB5J4%2Fsczy6gG8s%2FsA%3D%3D (https://ro.mouser.com/ProductDetail/Littelfuse/0PTF0078P?qs=Co4VkB5J4%2Fsczy6gG8s%2FsA%3D%3D) Transformer - *primary 2 x 115Vac region dependant* - secondary 36Vac + 36Vac at 5A

Selecting alternative parts
With current component shortage, it may happen that some parts listed in BOM to be unavailable, here are few alternative recommendations:
R16 - use a metal film resistor
C7 - use a good polypropylene made by Mundorf, Epcos, Vishay, CDC, U1 - following opamps can be used and will offer different sonic signatures: LME49710, LME49990, OPA604, OPA134, NE5534. Do not use TL071, TL081, LM301, LM741.
Q2 and Q3 - use transistors with Vce >= 65V & hFE>=100 : 2N5401 / 2N5551 Q7 and Q12 - other transistors that may be used are: KSC1845, 2N4401, BC546 / BC547 / BC548 / BC549 / BC550 - use the one with A termination for

Q7 and C termination for Q12.
C1 - this must be silver-mica or at least polystyrene.
Q1- KSA992, 2N4403, BC556C, BC557C, BC558C, BC559C, and BC560C C10 - silver-mica or ceramic NP0
R26, R27, R28 - these must be non-inductive resistors. MILLS make some good ones.
C17 - in this order: polystyrene, teflon, foil polypropilene, metalised polypropylene.
Q5 and Q6 - following pairs may be used with excellent performance: FQP3P50/FQP4N80; FQP4P40/FQP5N60
Q5 and Q6 - following pairs may be used with modest performance: IRF610/ IRF9610; IRF640/IRF9640; 2SJ76, 2SJ77, 2SJ78, 2SJ79 respectively 2SK213, 2SK214, 2SK215, 2SK216.
Q15,Q16,Q17,Q18 - following pairs can be used with modest performance IRFP9240/IRFP240; 2SJ201/2SK1530; 2SJ118/2SK413; 2SJ119/2SK414. Q9 and Q11 - Instead BS250 you may use ZVP3306A (https://ro.mouser.com/ProductDetail/Diodes-Incorporated/ZVP3306A?qs=vHuUswq2%252Bsyljxw%2Fl1wUQg%3D%3D)

Exicon ECW20N20 and ECW20P20 lateral MOSFET’s can NOT be used on this PCB. PCB need to be redesigned to accommodate lateral mosfet pinout.

Q17 Construction
Keep input shorted before any dc or static amplifier measurements. Static mean you only measure voltages in various places.
Start by installing operational and regulator with Q1-Q2-Q3-Q4. Next add Q13 and Q14 capacitor multipliers. Power up at and measure voltages before and after regulators. Before regulators you should measure +45Vdc/-46Vdc. After regulators you may expect around +13.5Vdc and -14Vdc
The two red LED, D1 and D4 must light on.
Mount the rest of parts, short input, power up and measure DC output. This must be under ~40mV.
Voltage across R3 and R13 must be between 500mV and 700mV. Voltage across R11 and R12 ~3V, a bit higher on R12.
If above measurements are OK, then you may connect Q17 amplifier to a preamplifier, potentiometer or volume controller. Connect output speakers trough a speaker protection module or a 3A fast fuse.
Take care and do not short the amplifier output. There is no protection, unless you have installed a separate one.
In some cases, a soft-start module is needed.

Building active power supply
For proper performance Q17 need a min.300VA transformer. There are E+I, C-core, R-core, Toroidal transformers. Any of them will work, but people ask which is the best. The best is the one that is the best constructed, using proper materials and well executed. However, from theoretical point of view, R-core exhibit lowest EM loss. A well executed R-core can be the best. Transformer must have dual separate secondary, 2 x 36Vac at min 5A.
Do not measure Saligny rectifiers without filter capacitors. Install all parts and measure when all is in place. Compared to any diode rectifier, Saligny rectifiers do not have voltage loss and you should get 36Vac x √2 = 50.9Vdc at active
Power supply output on each rail.

Measurements
Amplifier do not need specific adjustments and should work from the beginning. Please allow at least 48h for burn-in. Electrolytic capacitors are the most sensible at burn-in and some need 200h or more.
Mosfet transistors also need burn-in. My personal observation is that after 48h these are ok to go.
In order to perform burn-in, leave your amplifier powered ON. A musical program at low level will help as well.

What you should expect from this amplifier ?
Exceptional dynamics with superb harmonic extension. Strong and round bass. Exceptional midrange with crystal clear top response. Instrument separation localisation in deep 3D.
Enjoy & Thank you !

References and acknowledgements:
Current Dumping Audio Amplifier - PJ Walker - Wireless World, December 1975
Feedforward Error Correction in Power Amplifiers - Vanderkooy-Lipshitz Current dumping does it really work ? Theory and practice by J. Vanderkooy and S. P. Lipshitz University of Waterloo, Ontario
Current dumping analysis Class B amplifiers without crossover distorsion by H, S. Malvar, M. Sc. University of Brasilia
Test reports QUAD405 Current Dumping Amplifier by Gordon J. King Sources 101: Audio Current Regulator Tests for High Performance - Full Article by Walt Jung (https://audioxpress.com/authors/23384/walt-jung)

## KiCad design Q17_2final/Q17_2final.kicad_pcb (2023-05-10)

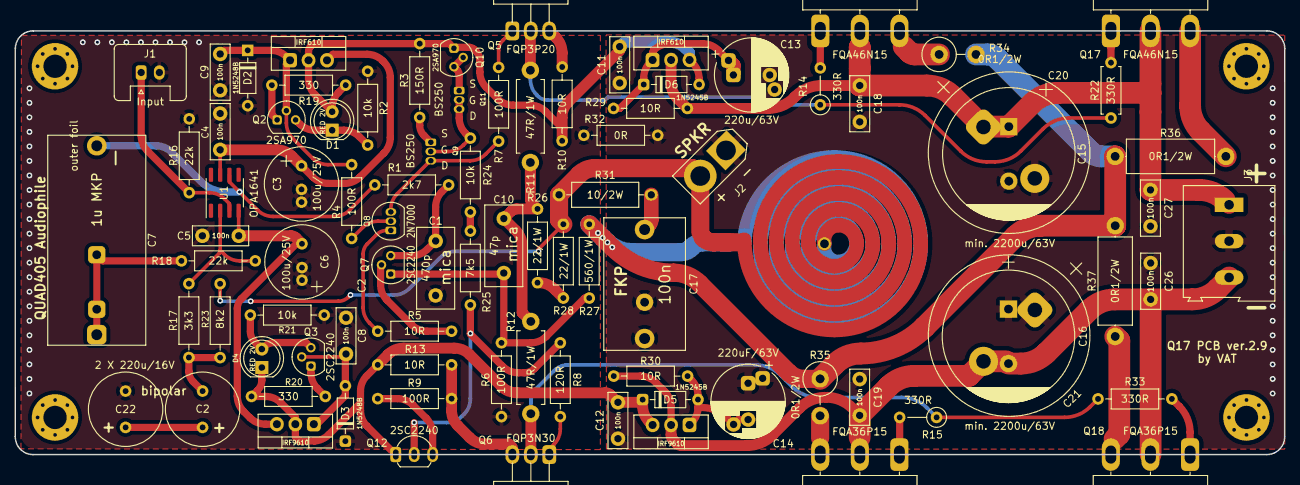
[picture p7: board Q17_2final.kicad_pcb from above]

Board: 2 copper layers, 174.7 x 58.3 mm, 94 parts (0 on the bottom side), 53 nets.

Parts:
C1: 470p; C_Disc_D11.0mm_W5.0mm_P7.50mm
C2: 220uF/16V; C_Radial_D10.0mm_H12.5mm_P5.00mm
C3, C6: 100u/25V; C_Radial_D10.0mm_H12.5mm_P5.00mm
C4, C5, C8, C9, C11, C12, C18, C19, C26, C27: 100n; C_Disc_D7.5mm_W2.5mm_P5.00mm
C7: 1u MKP; CP_Axial_L20.0mm_D13.0mm_P26.00mm_Horizontal
C10: 47p; C_Disc_D11.0mm_W5.0mm_P7.50mm
C13: 220u/63V; CP_Radial_D10.0mm_P5.00mm_P7.50mm
C14: 220uF/63V; CP_Radial_D10.0mm_P5.00mm_P7.50mm
C15, C16: 2200uF/63V; CP_Radial_D18.0mm_P7.50mm
C17: 100n; C_Rect_L18.0mm_W11.0mm_P15.00mm_FKS3_FKP3
C20, C21: min. 2200u/63V; CP_Radial_D22.0mm_P10.00mm_SnapIn
C22: 2 X 220u/16V; C_Radial_D10.0mm_H12.5mm_P5.00mm
D1, D4: RED 2V; LED_D5.0mm_Clear
D2, D3: 1N5248B; D_DO-35_SOD27_P7.62mm_Horizontal
D5, D6: 1N5245B; D_DO-35_SOD27_P7.62mm_Horizontal
H1, H1#2, H1#3, H1#4: MountingHole; MountingHole_3.2mm_M3_Pad_Via
J1: Input; Stocko_MKS_1651-6-0-202_1x2_P2.50mm_Vertical
J2: Screw_Terminal_01x02; AMASS_XT30U-F_1x02_P5.0mm_Vertical
J3: Screw_Terminal_01x03; TerminalBlock_Altech_AK300-3_P5.00mm
L1: 1u2; L_new
Q1, Q13: IRF610; TO-220-3_Vertical
Q2, Q10: 2SA970; TO-92
Q3, Q7: 2SC2240; TO-92
Q4, Q14: IRF9610; TO-220-3_Vertical
Q5: FQP3P20; TO-220-3_Horizontal_TabDown
Q6: FQP3N30; TO-220-3_Horizontal_TabDown
Q8: 2N7000; TO-92_Inline
Q9, Q11: BS250; TO-92L_Inline
Q12: 2SC2240; TO-92L_Inline_Wide
Q15, Q17: FQA46N15; TO-3P-3_Horizontal_TabDown
Q16, Q18: FQA36P15; TO-3P-3_Horizontal_TabDown
R1: 2k7; R_Axial_DIN0207_L6.3mm_D2.5mm_P10.16mm_Horizontal
R2, R21, R24: 10k; R_Axial_DIN0207_L6.3mm_D2.5mm_P10.16mm_Horizontal
R3: 150R; R_Axial_DIN0207_L6.3mm_D2.5mm_P10.16mm_Horizontal
R4, R6, R7, R9: 100R; R_Axial_DIN0207_L6.3mm_D2.5mm_P10.16mm_Horizontal
R5, R10, R13, R29, R30: 10R; R_Axial_DIN0207_L6.3mm_D2.5mm_P10.16mm_Horizontal
R8: 120R; R_Axial_DIN0207_L6.3mm_D2.5mm_P10.16mm_Horizontal
R11, R12: 47R/1W; R_Axial_DIN0411_L9.9mm_D3.6mm_P12.70mm_Horizontal
R14, R15: 330R; R_Axial_DIN0207_L6.3mm_D2.5mm_P5.08mm_Vertical
R16, R18: 22k; R_Axial_DIN0207_L6.3mm_D2.5mm_P10.16mm_Horizontal
R17: 3k3; R_Axial_DIN0207_L6.3mm_D2.5mm_P10.16mm_Horizontal
R19, R20: 330; R_Axial_DIN0207_L6.3mm_D2.5mm_P10.16mm_Horizontal
R22: 330R; R_Axial_DIN0207_L6.3mm_D2.5mm_P7.62mm_Horizontal
R23: 8k2; R_Axial_DIN0207_L6.3mm_D2.5mm_P10.16mm_Horizontal
R25: 7k5; R_Axial_DIN0207_L6.3mm_D2.5mm_P10.16mm_Horizontal
R26, R28: 22/1W; R_Axial_DIN0207_L6.3mm_D2.5mm_P10.16mm_Horizontal
R27: 560/1W; R_Axial_DIN0207_L6.3mm_D2.5mm_P10.16mm_Horizontal
R31: 10/2W; R_Axial_DIN0309_L9.0mm_D3.2mm_P12.70mm_Horizontal
R32: 0R; R_Axial_DIN0207_L6.3mm_D2.5mm_P10.16mm_Horizontal
R33: 330R; R_Axial_DIN0207_L6.3mm_D2.5mm_P10.16mm_Horizontal
R34, R35: 0R1/2W; R_Axial_DIN0414_L11.9mm_D4.5mm_P5.08mm_Vertical
R36, R37: 0R1/2W; R_Axial_DIN0414_L11.9mm_D4.5mm_P15.24mm_Horizontal
U1: OPA1641; SOIC-8_3.9x4.9mm_P1.27mm

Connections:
GND: C1.2, C3.2, C4.1, C5.1, C6.1, C8.1, C9.1, C22.1, D2.2 (A), D3.1 (K), J1.1, R2.2, R6.2, R16.1, R21.2, R32.1
GNDPWR: C11.1, C12.1, C13.2, C14.1, C15.2, C16.1, C17.2, C18.1, C19.2, C20.2, C21.1, C26.2, C27.1, J2.1, J3.2, R32.2
unnamed: C1.1, Q7.3 (B), R1.2
unnamed: C2.1, R17.1, R23.1
unnamed: C2.2, C22.2
unnamed: C3.1, C4.2, Q1.3 (S), U1.7 (V+)
unnamed: C5.2, C6.2, Q4.3 (S), U1.4 (V-)
unnamed: C7.1, R1.1, U1.6
unnamed: C7.2, R18.2
unnamed: C8.2, D3.2 (A), Q3.2 (C), Q4.1 (G)
unnamed: C9.2, D2.1 (K), Q1.1 (G), Q2.2 (C), R4.1
unnamed: C10.1, R11.2, R12.1, R26.1
unnamed: C10.2, Q7.1 (E), R6.1, R27.1
unnamed: C11.2, D1.2 (A), D6.2 (A), Q1.2 (D), Q10.1 (E), Q13.3 (S), R3.1, R10.1, R19.1
unnamed: C12.2, D4.1 (K), D5.1 (K), Q4.2 (D), Q12.1 (E), Q14.3 (S), R13.2, R20.1
unnamed: C13.1, D6.1 (K), Q13.1 (G), R29.2
unnamed: C14.2, D5.2 (A), Q14.1 (G), R30.1
unnamed: C15.1, C18.2, C20.1, C27.2, J3.1, Q13.2 (D), Q15.2 (D), Q17.2 (D), R29.1
unnamed: C16.2, C19.1, C21.2, C26.1, J3.3, Q14.2 (D), Q16.2 (D), Q18.2 (D), R30.2
unnamed: C17.1, R31.2
unnamed: D1.1 (K), Q2.3 (B), R2.1
unnamed: D4.2 (A), Q3.3 (B), R21.1
unnamed: J1.2, R16.2, U1.3 (+)
unnamed: J2.2, L1.1, R23.2, R28.2, R31.1
unnamed: L1.2, R27.2, R34.2, R35.1, R36.2, R37.1
unnamed: Q2.1 (E), R19.2
unnamed: Q3.1 (E), R20.2
unnamed: Q5.1 (G), R7.2
unnamed: Q5.2 (D), R11.1, R14.1, R22.1
unnamed: Q5.3 (S), R10.2
unnamed: Q6.1 (G), R8.2
unnamed: Q6.2 (D), R12.2, R15.1, R33.1
unnamed: Q6.3 (S), R9.2, R13.1
unnamed: Q7.2 (C), R5.2
unnamed: Q8.1 (S), R5.1
unnamed: Q8.2 (G), R4.2
unnamed: Q8.3 (D), Q9.3 (D), R7.1
unnamed: Q9.1 (S), R3.2
unnamed: Q10.2 (C), Q10.3 (B), Q11.1 (S)
unnamed: Q9.2 (G), Q11.2 (G), Q11.3 (D), R24.1
unnamed: Q12.2 (C), R8.1, R25.2
unnamed: Q12.3 (B), R9.1
unnamed: Q15.1 (G), R14.2
unnamed: Q15.3 (S), R34.1
unnamed: Q16.1 (G), R15.2
unnamed: Q16.3 (S), R35.2
unnamed: Q17.1 (G), R22.2
unnamed: Q17.3 (S), R36.1
unnamed: Q18.1 (G), R33.2
unnamed: Q18.3 (S), R37.2
unnamed: R17.2, R18.1, U1.2 (-)
unnamed: R24.2, R25.1
unnamed: R26.2, R28.1

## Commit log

2022-07-22 latest gerber files for 2 final output stage
2022-12-24 Q17 pcb dimensions
    Q17 pcb dimensions indicate most important parts max. size, distance between holes and placement.
2022-12-31 Latest Q17 PCB version 2.8
    [Q17_2final.kicad_pcb, Q17_2final.kicad_sch]
2022-12-31 Latest KiCad files for PCB ver.2.8
    [Q17_2final.kicad_pcb, Q17_2final.kicad_sch]
2022-12-31 KiCad files for Q17 2 pair pcb ver.2.8
    [Q17_2final.kicad_pcb, Q17_2final.kicad_sch]
2022-12-31 Production files for Q17 pcb ver.2.8
2023-05-10 Gerber files for Q17 pcb ver.2.9
